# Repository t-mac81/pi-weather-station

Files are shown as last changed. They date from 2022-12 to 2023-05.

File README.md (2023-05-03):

# Pi Weather Station <p align="left"> <a href="https://www.raspberrypi.org/" target="_blank" rel="noreferrer"> raspberrypi </a><a href="https://www.arduino.cc/" target="_blank" rel="noreferrer"> arduino </a> <a href="https://www.python.org" target="_blank" rel="noreferrer"> python </a><a href="https://www.w3schools.com/cpp/" target="_blank" rel="noreferrer"> cplusplus </a></p>

This is a hardware/software project for an off grid solar powered weather station with webcam that posts to the internet via a cellular modem. Wind speed, wind direction and temperature are recorded. The project was completed in 2017/2018. As of May 2023 there is still a unit in service at a paragliding launch in Vernon, BC Canada.

## Hardware

A raspberry pi-zero is used in combination with a sleepy-pi board (arduino + real time clock) and a custom printed circuit board for analog to digital conversion for the anemometer and battery voltage. A Hologram Nova LTE-M1 cellular modem is used for internet connection. A 25W solar panel with solar controller is used to charge an 8Ah 12V lead acid battery. The anemometer is an off the shelf Davis 6410

The custom printed circuit board design file contains full electrical schematics and is located in the [fritzing folder](./fritzing/) Fritzing software is required to open the file and can be downloaded from their website in the [links](#links) section.

PCB features:

- An RJ11 connector for the davis 6410 anemometer
- MCP3008 analog to digital converter
- 12V voltage divider circuit with 20K trim pot for calibration
- DS18B20 digital temperature sensor

A full parts list is located in the [parts_list folder](./parts_list/)

<p align="middle">
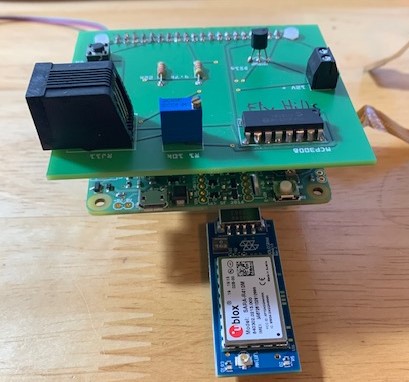
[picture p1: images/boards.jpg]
  
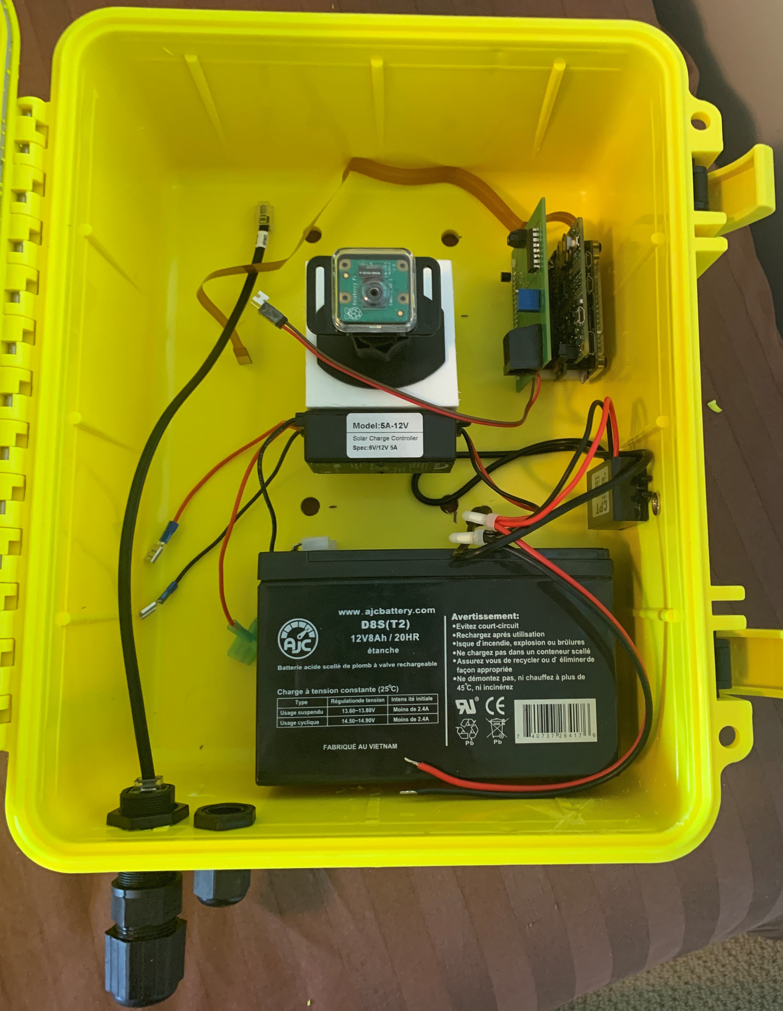
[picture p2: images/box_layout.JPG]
  
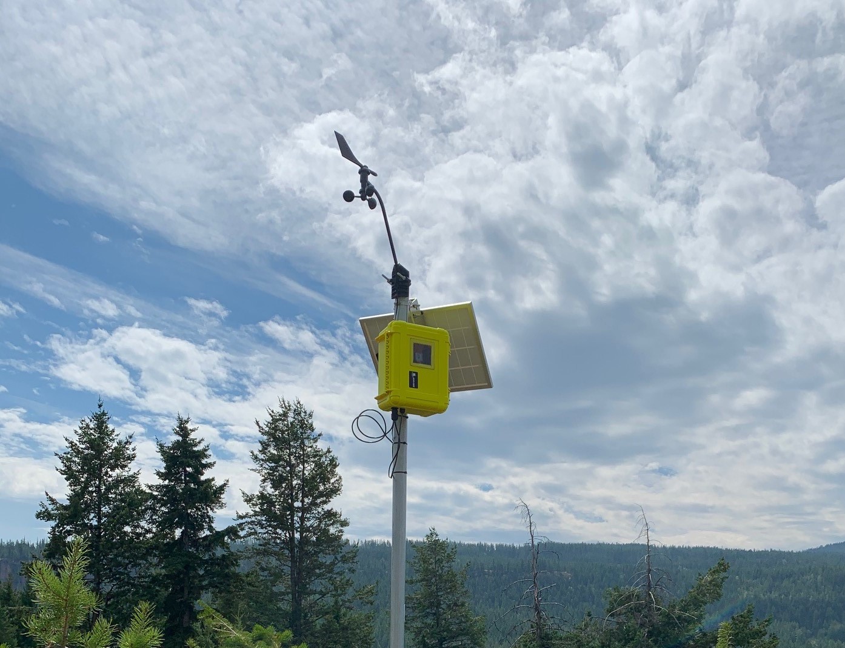
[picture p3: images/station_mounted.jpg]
  
  </p>
<br/>

## Software

This was my first programing project, I had not touched python prior to the project and didn't understand how to properly structure code. The code works well but it's not pretty. I would like to revisit this project down the road and create a revised design based on everything I've learned to date.

### [Python files](./python_files/)

- [voltage_calibration.py](./python_files/voltage_calibration.py) - used to calibrate the 12V voltage divider circuit which is used to display battery voltage on the webcam and shutdown the pi in case of low voltage.

- [weather_read.py](./python_files/weather_read.py) - every 15 min collects wind speed (min, peak, avg.), direction, temperature and battery voltage, sends data to windguru API and uploads webcam photo to webcam.io.

### [Arduino Files](./sleepy-pi-arduino/)

- [sleepypi.ino](./sleepy-pi-arduino/sleepypi.ino) - config file for the arduino/RTC which turns the raspberry pi on in the morning and off at night to conserve battery. It also keeps the raspberry pi powered down over the winter months to ensure the battery stays charged and doesn't freeze. The paragliding sites are not flown in the winter so there was no need to keep the stations online in the winter months.

### [Crontab](./crontab/)

- [crontab.txt](./crontab/crontab.txt) -this runs the weather_read.py script every 15 minutes while the raspberry pi is booted. It also clears the logs once a month to keep the SD card from getting full.

### [Hologram chat script](./chatscript/)

- This folder contains the location of the cellular modem chat script on the raspberry pi as well as the [chat script](./chatscript/default-script.txt) itself. The chat script needs to be modified based on the IP for your cellular provider.

## Website

The website is a very simple design on weebly which combines responsive widgets from windguru and webcam.io to make the data view well on mobile and desktop devices.

<p align="middle">
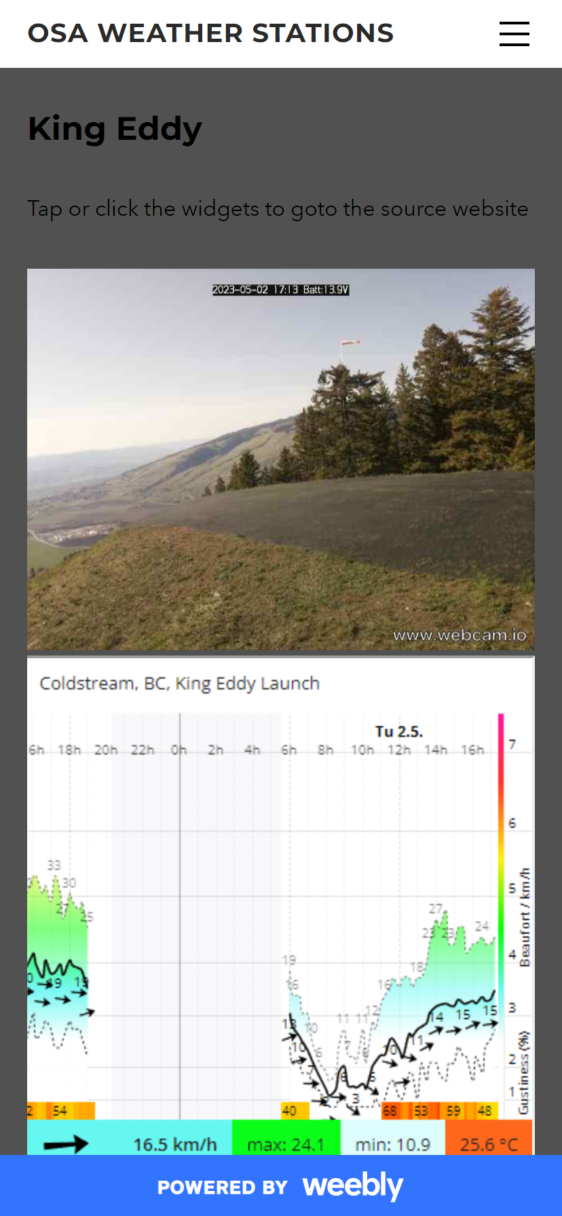
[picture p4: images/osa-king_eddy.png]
  
    </p>
<br/>

## Credits

[BC Robotics](https://bc-robotics.com/tutorials/raspberry-pi-weather-station-part-2/) has a great tutorial that i used to help figure out how to read the digital temperature sensor and anemometer data with the raspberry pi and a mcp3008 A/D converter

## Links

[OSA Weather](https://osa-weather.weebly.com) - Weather station website. Note that the stations are offline until the end of March.

[Windguru](https://www.windguru.cz) - Hosting for the weather station data. They have a fairly straightforward API using an http GET request.

[webcam.io](https://webcam.io) - Hosting for the webcam images via FTP.

[Fritzing](https://www.fritzing.org) - PCB design software

[Spellfoundry](https://spellfoundry.com/) - sleepy-pi RTC board.

[Hologram](https://www.hologram.io/) - Hologram Nova cellular modem

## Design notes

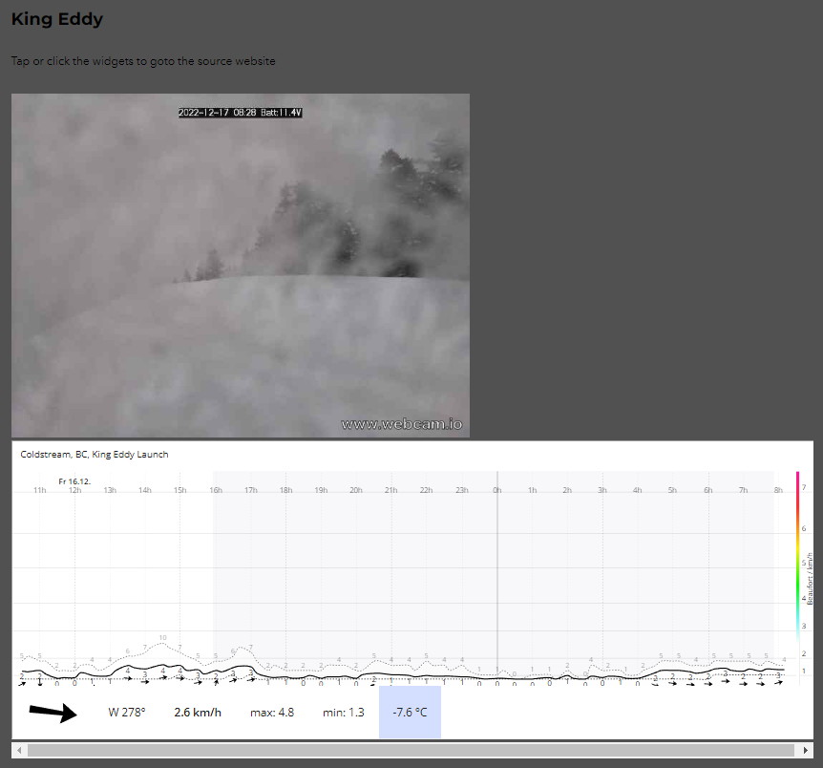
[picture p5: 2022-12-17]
images/king_eddy.PNG

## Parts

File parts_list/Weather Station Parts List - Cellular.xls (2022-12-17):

Major Components (per station) | Link
Raspberry Pi Zero (non wifi version) | https://www.buyapi.ca/product/raspberry-pi-zero/
Pi camera | https://www.amazon.ca/gp/product/B01ER2SKFS/ref=ppx_yo_dt_b_asin_title_o00_s00?ie=UTF8&psc=1
Pi camera case | https://www.adafruit.com/product/3253
Pi camera mount | https://www.amazon.com/Holder-Mobius-Action-Sports-Camera/dp/B01HMZCS1Y
Pi Camera Cable | https://www.amazon.ca/gp/product/B07JBD9XGB/ref=ppx_yo_dt_b_asin_title_o08_s00?ie=UTF8&psc=1
Pi zero case | https://www.buyapi.ca/product/adafruit-pi-protector-for-raspberry-pi-model-zero/
usb OTG adapter for NOVA modem | https://www.ebay.ca/itm/Micro-USB-Male-to-USB-Female-OTG-Adapter-Converter-For-Tablet-Android-Phone/292075891195
Sleepy Pi Board | https://www.buyapi.ca/product/sleepy-pi-power-management-shield-for-raspberry-pi-a-and-b/
12V usb power adapter | https://www.amazon.ca/gp/product/B00QTJWRFW/ref=ppx_yo_dt_b_asin_title_o09_s00?ie=UTF8&psc=1
12V 8ah Battery | https://www.amazon.ca/gp/product/B00A82GN74/ref=ppx_yo_dt_b_asin_title_o07_s00?ie=UTF8&psc=1
RJ45 Cable gland | https://www.buyapi.ca/product/cable-gland-waterproof-rj-45-ethernet-connector-rj-45/
solar panel pole mount | https://www.ebay.ca/itm/Renogy-Pole-Wall-Mount-Aluminum-Tilt-Mounting-Bracket-For-30W-50W-Solar-Panel/254015580998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
2" u-bolts for box mounting | (home depot)
Solar charge controller | https://www.amazon.ca/gp/product/B01C5O0DVY/ref=ppx_yo_dt_b_asin_title_o08_s00?ie=UTF8&psc=1
20-25w solar panel | https://www.amazon.ca/ACOPOWER%C2%AE-Polycrystalline-Photovoltaic-Battery-Charger/dp/B01LY8MQGY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 (https://www.amazon.ca/ACOPOWER®-Polycrystalline-Photovoltaic-Battery-Charger/dp/B01LY8MQGY?cv_ct_cx=25w+solar&pf_)
Davis 6410 Anemometer | https://www.amazon.ca/Davis-Instruments-Anemometer-Vantage-Pro2/dp/B004GK9MFO?s=gateway
Hologram Nova cellular modem | https://www.digikey.ca/en/products/detail/hologram-inc/HOL-NOVA-R410/9489897
UK 6510 Enclosure | https://www.underwaterkineticscanada.com/products/view-product/t-6510
Custom circuit boards (.fzz file included in email) | https://aisler.net/
Circuit Board components (per board)
DS18B20 temp sensor | https://www.amazon.ca/DS18B20-1-Wire-Digital-Thermometer-Dallas/dp/B00AYE2T2O?cv_ct_cx=ds18b20
20K Trim pot (set to 6.21 kohms) for 12V voltage divider | https://www.amazon.ca/DealMux-3296W-203-Resistor-Potentiometer-Trimmer/dp/B071KKJ4Y5
4.7kohm resistor | Buy a pack of various resistors or whatever works best
22kohm resistor | Buy a pack of various resistors or whatever works best
MCP3008 A/D converter chip | https://www.amazon.ca/Microchip-MCP3008-I-10-Bit-ADC-Pack/dp/B01HGCSGXM?s=industrial
Pushbuttons (2) | https://www.amazon.ca/dp/B01MQYU3ZA/ref=pe_3034960_233709270_TE_item
RJ11 adapter | https://www.sparkfun.com/products/132
Terminal block for 12V | https://elmwoodelectronics.ca/products/terminal-block-2-pin-3-5mm-pack-of-5
circuit board header (plugs into pi/sleepy pi headers) | https://www.buyapi.ca/product/40-pin-gpio-connector-header/
Components Total: | not including shipping or taxes
Recommended Items for setup, testing and Programming
Pi 3B+ or Pi 4 for testing and programming | https://www.buyapi.ca/product/raspberry-pi-3-model-b-plus-bulk-purchase/
fan for testing anemometer

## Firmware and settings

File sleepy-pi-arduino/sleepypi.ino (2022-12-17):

// 
// Simple example showing how to set the RTC alarm pin to wake up the Arduino.
// Like an alarm clock the alarm is triggered at a particular time and 
// then the Arduino wakes up.
// Also wakes and sleeps on rising edge of button press

// In this example two times are set: 
//      Wakeup time = Time to awake
//      Bedtime     = Time to go back to Sleep
//
// 
// Note: this example doesn't wake up the RPi. For that add:
//
//     SleepyPi.enablePiPower(true);  
//
// after arduino wakeup. 
// 
// To test on the RPi without power cycling and using the Arduino IDE
// to view the debug messages, fit the Power Jumper or enable
// self-power
// 
// 

// **** INCLUDES *****
#include "SleepyPi2.h"
#include <Time.h>
#include <LowPower.h>
#include <PCF8523.h>
#include <Wire.h>

const char *monthName[12] = {
  "Jan", "Feb", "Mar", "Apr", "May", "Jun",
  "Jul", "Aug", "Sep", "Oct", "Nov", "Dec"
}; 

const int LED_PIN = 13;

// Globals (Time in UTC)
// ++++++++++++++++++++ Change me ++++++++++++++++++
uint8_t  WakeUp_StartHour       = 12;  // Hour in 24 hour clock wake: 5:35am
uint8_t  WakeUp_StartMinute     = 35;  // Minutes 
uint8_t  Bedtime_SleepHour      = 01;  // Hour in 24 hour clock sleep: 6:10pm
uint8_t  Bedtime_SleepMinute    = 10;  // Minutes 

// ++++++++++++++++++++ End Change me ++++++++++++++++++

tmElements_t tm;
bool  pi_awake = false;

void alarm_isr()
{
    // Just a handler for the alarm interrupt.
    // You could do something here
}

void setup()
{
  // Configure "Standard" LED pin
  pinMode(LED_PIN, OUTPUT);		
  digitalWrite(LED_PIN,LOW);		// Switch off LED
  // initialize serial communication: In Arduino IDE use "Serial Monitor"
  Serial.begin(9600);
  Serial.println("Starting...");
  delay(50);
  
  SleepyPi.rtcInit(true);

  // Default the clock to the time this was compiled.
  // Comment out if the clock is set by other means
  // ...get the date and time the compiler was run
  if (getDate(__DATE__) && getTime(__TIME__)) {
      // and configure the RTC with this info
  //    SleepyPi.setTime(DateTime(F(__DATE__), F(__TIME__)));
  }  

  printTimeNow();
  
  Serial.print("Alarm Set for: ");
  Serial.print(WakeUp_StartHour);
  Serial.print(":");
  Serial.println(WakeUp_StartMinute);

  Serial.print("Bedtime Set for: ");
  Serial.print(Bedtime_SleepHour);
  Serial.print(":");
  Serial.println(Bedtime_SleepMinute);
  
}

void loop() 
{
  
    if(pi_awake == false)
    {
        SleepyPi.rtcClearInterrupts();
      
        // Allow wake up alarm to trigger interrupt on falling edge.
        attachInterrupt(0, alarm_isr, FALLING);   // Alarm pin
        attachInterrupt(1, alarm_isr, RISING);   // button pin to wake on button press
        SleepyPi.enableWakeupAlarm(true);
        
        // Setup the Alarm Time
        SleepyPi.setAlarm(WakeUp_StartHour,WakeUp_StartMinute);   // Hours & Minutes i.e. 22:07 on the 24 hour clock         
        
        //PrintRTCRegisters();   // for debug
        delay(500);   // Delay purely for serial print
                
        // Enter power down state with ADC and BOD module disabled.
        // Wake up when wake up pin is low (which occurs when our alarm clock goes off)
        SleepyPi.powerDown(SLEEP_FOREVER, ADC_OFF, BOD_OFF); 
        
        // Disable external pin interrupt on wake up pin.
        detachInterrupt(0);        
        SleepyPi.ackAlarm();
        
        // Do something here
        // Example: Read sensor, data logging, data transmission.
        // Just a handler for the pin interrupt.
        digitalWrite(LED_PIN,HIGH);   // Switch on LED
        Serial.println("I've Just woken up on the Alarm!");
        // Print the time
        printTimeNow();   
        delay(50);
        digitalWrite(LED_PIN,LOW);    // Switch off LED
        
        // +++++ Power the Rpi ++++++
        //only power up from March 1 to Sept 30
        DateTime now = SleepyPi.readTime();
        if(now.month() > 2 && now.month() < 10)
        {
          SleepyPi.enablePiPower(true); 
          pi_awake = true;
        } 
     }
     else
     {
          // pi awake                
          SleepyPi.rtcClearInterrupts();
        
          // Allow wake up alarm to trigger interrupt on falling edge.
          attachInterrupt(0, alarm_isr, FALLING);   // Alarm pin
          attachInterrupt(1, alarm_isr, RISING);   // button pin to sleep on button press
          SleepyPi.enableWakeupAlarm(true);
          
          // Setup the Alarm Time
          SleepyPi.setAlarm(Bedtime_SleepHour,Bedtime_SleepMinute);   // Hours & Minutes i.e. 22:07 on the 24 hour clock    
  
          delay(500); // Delay purely for serial print
               
          // Enter power down state with ADC and BOD module disabled.
          // Wake up when wake up pin is low (which occurs when our alarm clock goes off)
          SleepyPi.powerDown(SLEEP_FOREVER, ADC_OFF, BOD_OFF); 
          
          // Disable external pin interrupt on wake up pin.
          detachInterrupt(0); 
          SleepyPi.ackAlarm();              
     
          // Do something here
          // Just a handler for the pin interrupt.
          digitalWrite(LED_PIN,HIGH);   // Switch on LED
          Serial.println("I've Just gone to bed...zzzzzzzz");
          // Print the time
          printTimeNow();   
          delay(50);
          digitalWrite(LED_PIN,LOW);    // Switch off LED
        
        // ++++++ uncomment to Power-down the Rpi ++++++++
        SleepyPi.piShutdown();         
          pi_awake = false;            
     }
  
}

void printTimeNow()
{
    // Read the time
    DateTime now = SleepyPi.readTime();
    
    // Print out the time
    Serial.print("Ok, Time = ");
    print2digits(now.hour());
    Serial.write(':');
    print2digits(now.minute());
    Serial.write(':');
    print2digits(now.second());
    Serial.print(", Date (D/M/Y) = ");
    Serial.print(now.day());
    Serial.write('/');
    Serial.print(now.month()); 
    Serial.write('/');
    Serial.print(now.year(), DEC);
    Serial.println();

    return;
}
bool getTime(const char *str)
{
  int Hour, Min, Sec;

  if (sscanf(str, "%d:%d:%d", &Hour, &Min, &Sec) != 3) return false;
  tm.Hour = Hour;
  tm.Minute = Min;
  tm.Second = Sec;
  return true;
}

bool getDate(const char *str)
{
  char Month[12];
  int Day, Year;
  uint8_t monthIndex;

  if (sscanf(str, "%s %d %d", Month, &Day, &Year) != 3) return false;
  for (monthIndex = 0; monthIndex < 12; monthIndex++) {
    if (strcmp(Month, monthName[monthIndex]) == 0) break;
  }
  if (monthIndex >= 12) return false;
  tm.Day = Day;
  tm.Month = monthIndex + 1;
  tm.Year = CalendarYrToTm(Year);
  return true;
}

void print2digits(int number) {
  if (number >= 0 && number < 10) {
    Serial.write('0');
  }
  Serial.print(number);
}

void PrintRTCRegisters(void)
{
  
      // Debug
      uint8_t reg_value;
      reg_value = SleepyPi.rtcReadReg(PCF8523_CONTROL_1);
      Serial.print("Control 1: 0x");
      Serial.println(reg_value,HEX);
      reg_value = SleepyPi.rtcReadReg(PCF8523_CONTROL_2);
      Serial.print("Control 2: 0x");
      Serial.println(reg_value, HEX);      
      reg_value = SleepyPi.rtcReadReg(PCF8523_CONTROL_3);
      Serial.print("Control 3: 0x");
      Serial.println(reg_value,HEX); 
      
      reg_value = SleepyPi.rtcReadReg(PCF8523_SECONDS);
      Serial.print("Seconds: ");
      Serial.println(reg_value,HEX);
      reg_value = SleepyPi.rtcReadReg(PCF8523_MINUTES);
      Serial.print("Minutes: ");
      Serial.println(reg_value,HEX);  
      reg_value = SleepyPi.rtcReadReg(PCF8523_HOURS);
      Serial.print("Hours: ");
      Serial.println(reg_value,HEX);  
      reg_value = SleepyPi.rtcReadReg(PCF8523_DAYS);
      Serial.print("Days: ");
      Serial.println(reg_value,HEX);   
      reg_value = SleepyPi.rtcReadReg(PCF8523_WEEKDAYS);
      Serial.print("Week Days: ");
      Serial.println(reg_value,HEX);    
      reg_value = SleepyPi.rtcReadReg(PCF8523_MONTHS);
      Serial.print("Months: ");
      Serial.println(reg_value,HEX);  
      reg_value = SleepyPi.rtcReadReg(PCF8523_YEARS);
      Serial.print("Years: ");
      Serial.println(reg_value,HEX); 
      
      reg_value = SleepyPi.rtcReadReg(PCF8523_MINUTE_ALARM);
      Serial.print("Minute Alarm: ");
      Serial.println(reg_value,HEX);      
      reg_value = SleepyPi.rtcReadReg(PCF8523_HOUR_ALARM);
      Serial.print("Hour Alarm: ");
      Serial.println(reg_value,HEX);  
      reg_value = SleepyPi.rtcReadReg(PCF8523_DAY_ALARM);
      Serial.print("Day Alarm: ");
      Serial.println(reg_value,HEX);      
      reg_value = SleepyPi.rtcReadReg(PCF8523_WEEKDAY_ALARM);
      Serial.print("Weekday Alarm: ");
      Serial.println(reg_value,HEX); 
      
      reg_value = SleepyPi.rtcReadReg(PCF8523_OFFSET);
      Serial.print("Offset: 0x");
      Serial.println(reg_value,HEX); 
      reg_value = SleepyPi.rtcReadReg(PCF8523_TMR_CLKOUT_CTRL);
      Serial.print("TMR_CLKOUT_CTRL: 0x");
      Serial.println(reg_value,HEX);  
      reg_value = SleepyPi.rtcReadReg(PCF8523_TMR_A_FREQ_CTRL);
      Serial.print("TMR_A_FREQ_CTRL: 0x");
      Serial.println(reg_value,HEX); 
      reg_value = SleepyPi.rtcReadReg(PCF8523_TMR_A_REG);
      Serial.print("TMR_A_REG: 0x");
      Serial.println(reg_value,HEX);     
      reg_value = SleepyPi.rtcReadReg(PCF8523_TMR_B_FREQ_CTRL);
      Serial.print("TMR_B_FREQ_CTRL: 0x");
      Serial.println(reg_value,HEX);    
       reg_value = SleepyPi.rtcReadReg(PCF8523_TMR_B_REG);
      Serial.print("TMR_B_REG: 0x");
      Serial.println(reg_value,HEX);     
 
}

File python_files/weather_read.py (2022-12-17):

#!/usr/bin/env python3

#import libraries
import busio
import digitalio
import os
import glob
import board
import adafruit_mcp3xxx.mcp3008 as MCP
import time
import picamera
from picamera import Color
import math
import ftplib
import hashlib
import datetime
import http.client
import subprocess
from statistics import mean
import RPi.GPIO as GPIO
from adafruit_mcp3xxx.analog_in import AnalogIn

#setup MCP3008
spi = busio.SPI(clock=board.SCK, MISO=board.MISO, MOSI=board.MOSI)
cs = digitalio.DigitalInOut(board.D5)
mcp = MCP.MCP3008(spi, cs)

#setup inputs for wind speed, direction, and battery voltage
wind_dir_raw= AnalogIn(mcp,MCP.P0) #create wind direction analog channel on MCP3008 pin 0
batt_raw = AnalogIn(mcp,MCP.P1) #create battery voltage analog channel on MCP3008 pin 1 for webcam text
windtick = 0 #used to count the number of times the wind speed input is triggered (GPIO21)
GPIO.setmode(GPIO.BCM) #Set GPIO pins to use BCM pin numbers
GPIO.setup(21,GPIO.IN, pull_up_down=GPIO.PUD_UP) #Setup GPIO21 to an input and enable the pullup

#setup temperature probe input and read temperature in degrees C
os.system('modprobe w1-gpio')
os.system('modprobe w1-therm')
base_dir = '/sys/bus/w1/devices/'
device_folder = glob.glob(base_dir + '28*')[0]
device_file = device_folder + '/w1_slave'

def read_temp_raw():
    catdata = subprocess.Popen(['cat',device_file], stdout=subprocess.PIPE, stderr=subprocess.PIPE)
    out,err = catdata.communicate()
    out_decode = out.decode('utf-8')
    lines = out_decode.split('\n')
    return lines

def read_temp():
    lines = read_temp_raw()
    while lines[0].strip()[-3:] != 'YES':
        time.sleep(0.2)
        lines = read_temp_raw()
    equals_pos = lines[1].find('t=')
    if equals_pos != -1:
        temp_string = lines[1][equals_pos+2:]
        temp_c = float(temp_string) / 1000.0
        return temp_c

#event to detect wind ticks
GPIO.add_event_detect(21, edge=GPIO.FALLING, bouncetime=30)
def windtrig(self):
    global windtick
    windtick +=1
GPIO.add_event_callback(21,windtrig)

#create lists to store wind speed and direction readings
store_windspeed = []
wind_dir_sin = []
wind_dir_cos = []

#create loop to collect and log wind speed, direction and temperature
interval = 3 #sample period for wind speed and direction in seconds

for i in range(1, 264): #run collection loop 264 times = 13.75 minutes
    time.sleep(interval) #set collection loop duration

    wind_dir_scaled = ((wind_dir_raw.value*360)/65472) #scale the wind direction
    wind_dir_rounded = (wind_dir_scaled) #and round it to one decimal place
    windspeed_mph = windtick * (2.25 / interval) #Calculate windspeed in mph
    windspeed_kts = (windspeed_mph * 0.868976) #convert windspeed to kts (windguru take knots)
    
    #append lists for data loging
    wind_dir_sin.append (math.sin(math.radians(wind_dir_rounded)))
    wind_dir_cos.append (math.cos(math.radians(wind_dir_rounded)))
    store_windspeed.append (windspeed_kts)
    #store_temp.append (temp)
    #print('wind direction: ', wind_dir_rounded ,'degrees')
    #print('wind speed: ', windspeed_kts, 'kts')
    #print('temperature: ', temp, 'degrees C')
    windtick = 0
wind_dir_avg_rad = math.atan2(mean(wind_dir_sin), mean(wind_dir_cos)) #calculation for the vector mean of wind direction in radians
wind_dir_avg = round((math.degrees(wind_dir_avg_rad))) #convert above output to degrees in +180 to -180 format

#if function to convert negative average wind direction
if wind_dir_avg < 0:
    wind_dir_avg_pos = wind_dir_avg + 360
if wind_dir_avg >= 0:
    wind_dir_avg_pos = wind_dir_avg

#Calculate min, max and average wind speeds, temperature and battery voltage
wind_speed_min = round(min(store_windspeed),1)
wind_speed_max = round(max(store_windspeed),1)
wind_speed_avg = round(mean(store_windspeed),1)
temperature = round(read_temp(),1)
batt_voltage_raw = batt_raw.voltage #scale volatge input to 0-3.3V=0-15V
batt_voltage = round(((batt_voltage_raw * 15)/3.3/0.991),1)

#setup variables for upload to windguru
date_time = datetime.datetime.now().strftime('%Y%m%d%H%M')
salt = date_time #use time string in YYYYMMDDHHMM format with time in 24 hour clock
uid = 'flyhills_launch' #weather station unit ID on wind guru
station_password = 'sportbiker6'
#url = '82.208.41.65'
url = 'www.windguru.cz'

#create md5 hash string and upload string for weather data
hash_string = salt +uid +station_password
hash_string_md5 = hashlib.md5(hash_string.encode())
hash_string_md5_hex = hash_string_md5.hexdigest() #hex md5 string for windguru upload
upload_string = '/upload/api.php?uid=' +str(uid) +'&salt=' +str(salt) +'&hash=' +str(hash_string_md5_hex) \
                +'&wind_avg=' +str(wind_speed_avg) +'&wind_min=' +str(wind_speed_min) +'&wind_max=' \
                +str(wind_speed_max) +'&wind_direction=' +str(wind_dir_avg_pos) +'&temperature=' +str(temperature) # need to add measurement interval


#take picture with webcam and add date, time and battery voltage
cam_date = datetime.datetime.now().strftime('%Y-%m-%d %H:%M')
cam_text = (cam_date +' Batt:' +str(batt_voltage) +'V')

with picamera.PiCamera() as camera:
    camera.resolution = (640,480)
    camera.rotation = 0
    camera.annotate_text_size = 15
    camera.annotate_background = Color('black')
    camera.annotate_text = (cam_text)
    #picam warmup time
    time.sleep(2)
    camera.capture('/var/log/weather_pic/picture.jpg', quality = 6) 

print ('average wind direction: ', wind_dir_avg_pos, 'degrees')
print ('minimum wind speed: ', wind_speed_min, 'kts')
print ('maximum wind speed: ', wind_speed_max, 'kts')
print ('average wind speed: ', wind_speed_avg, 'kts')
print ('average temperature: ', temperature, 'degrees C')
#print ('battery voltage: ' , batt_voltage, 'V')
#print (url +upload_string)
print (cam_text)

#Establish PPP session with hologram NOVA
connect_tries = 2
while connect_tries > 0:
    modem_con = subprocess.check_output(['sudo', 'hologram', 'network', 'connect']).decode('utf-8')
    print (modem_con.strip())
    if modem_con.strip() == 'PPP session started':
        print ('modem connection sucessful')
        break
    connect_tries = connect_tries-1
    print ('modem connection failed', connect_tries, 'attempts(s) left')
    time.sleep(4)
    if connect_tries == 1:
        print ('modem connection failed, resetting R410M modem')
        modem_reset = subprocess.check_output(['sudo', 'hologram', 'modem', 'reset']).decode('utf-8')
        print (modem_reset.strip())
        time.sleep(4)
time.sleep(3)
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
